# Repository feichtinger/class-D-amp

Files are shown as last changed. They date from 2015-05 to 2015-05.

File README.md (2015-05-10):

# class-D amplifier

This is a construction kit for a neat 2x5W class-D stereo amplifier.

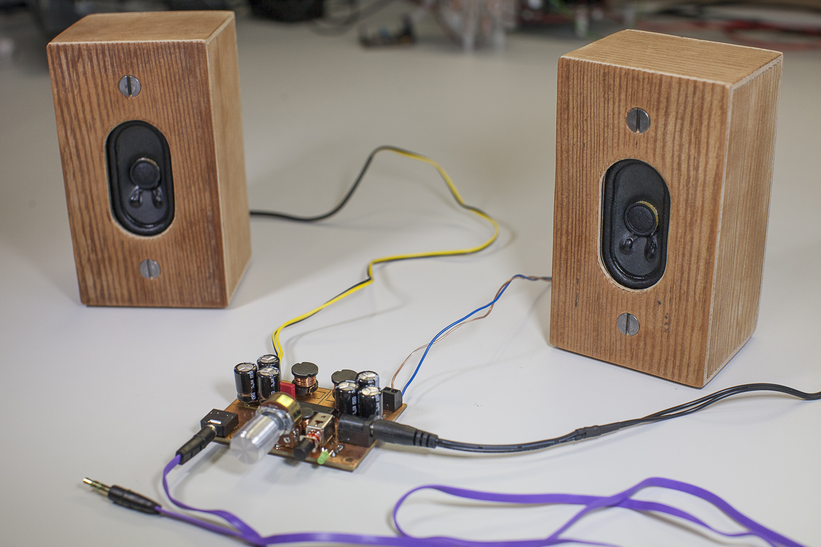
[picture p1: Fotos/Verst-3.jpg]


## purpose
This kit was developed together with Thomas Voglhuber at the [Insitute for Microelectronics and Microsensors](http://www.ime.jku.at) at the Johannes Kepler University.

It is especially designed to be easy to solder even for beginners and may be used for workshops with students or trainees.

The kit provides all components (including power supply and a pair of speakers) that are necessary to build a cute homemade stereo system.

## technical details
The circuit is based on a TPA3125D2 chip with only a view minor extensions such as volume controll and a power switch. Due to the digital operation principle the amplifier reaches a good performance with very low power disspation. Although the circuit was designed for 16 Ohm speakers the chip and the circuit can easily handle even 4 Ohm speakers to gain more output power without the need of a heatsink.

The schematic and PCB layout was made using [KiCad](http://www.kicad-pcb.org/display/KICAD/KiCad+EDA+Software+Suite). The PCB layout was designed with respect to the basic rules of power electronics such as separation of power and signal current traces and keeping high frequency current traces as short as possible.

This is open hardware, so feel free to build, change and improve things!

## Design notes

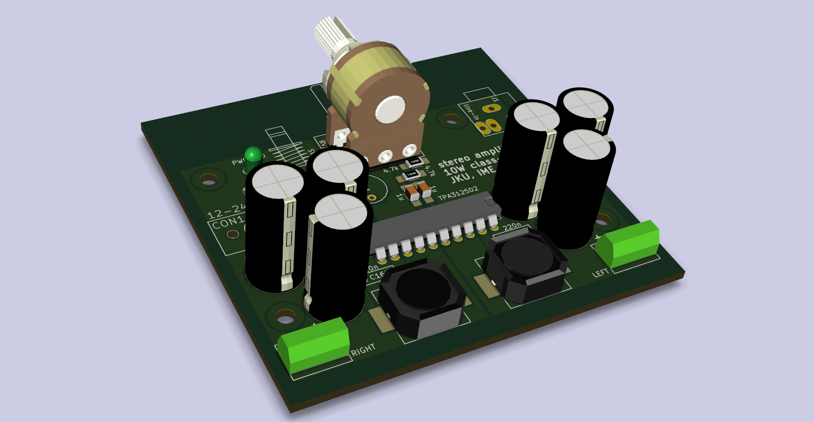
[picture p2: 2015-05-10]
KiCad/images/class-D_amp_3D_2.png

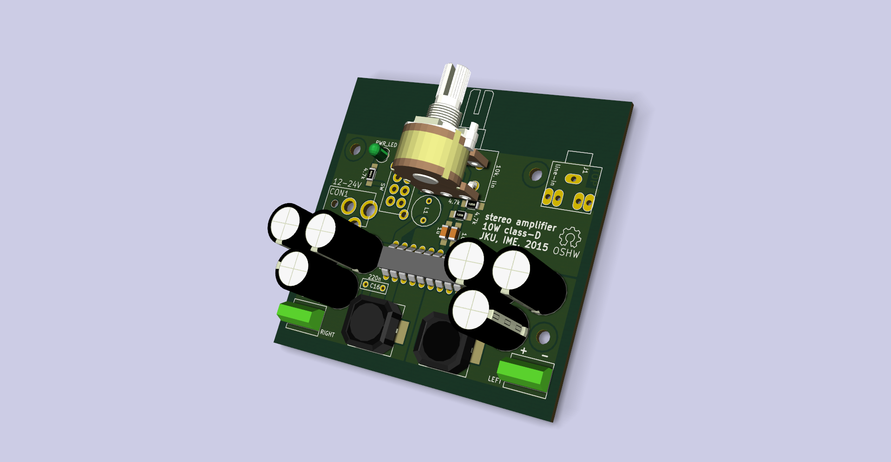
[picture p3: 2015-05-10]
KiCad/images/class-D_amp_3D_1.png

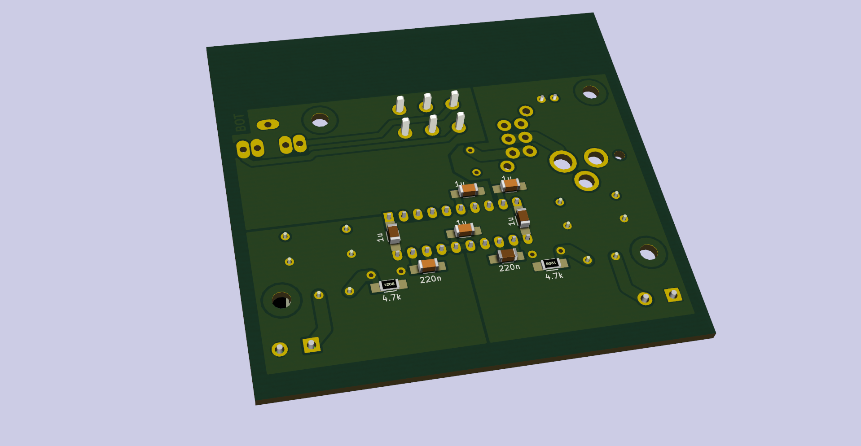
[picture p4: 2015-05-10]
KiCad/images/class-D_amp_3D_3.png

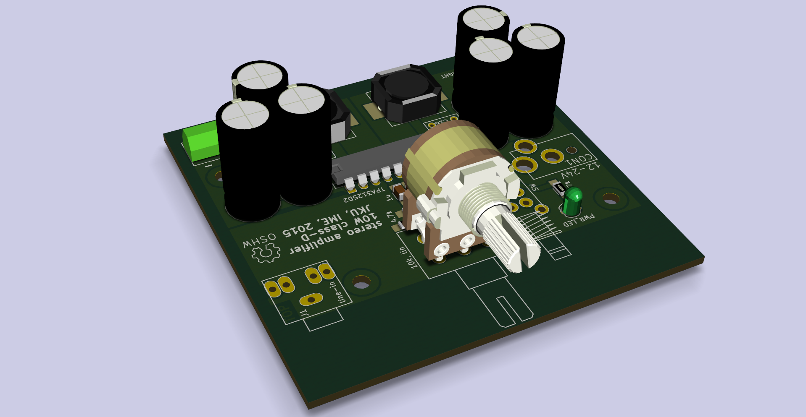
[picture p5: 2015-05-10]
KiCad/images/class-D_amp_3D_4.png

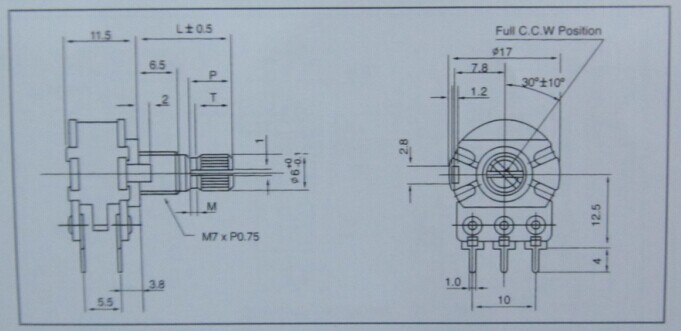
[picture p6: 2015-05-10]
Datenblätter/stereo_poti.jpg

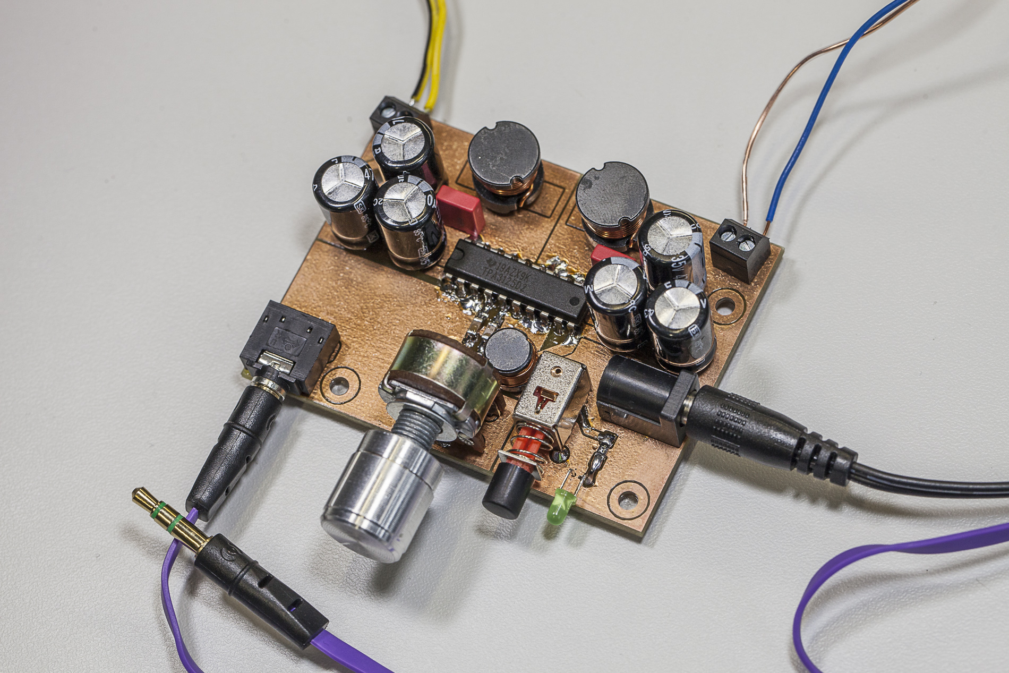
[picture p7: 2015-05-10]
Fotos/Verst-4.jpg

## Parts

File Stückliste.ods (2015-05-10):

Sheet: Tabelle1
Stückliste für class-D Verstärker
Stückzahl | Beschreibung | Wert | Abmessungen (in mm) | Händler | Artikelnummer | Stück gesamt | Einzelpreis € | Gesamtpreis €
5 | Widerstand | 4.7k | 1206 | Reichelt | SMD 1/4W 4,7K | 250 | 0,026 | 0,13
9 | Keramikkondensator | 1u | 1206 | Reichelt | X7R-G1206 1,0/50 | 450 | 0,04 | 0,36
2 | Folienkondensator, MKT | 220n | RM 5, 2.5x7.5 | Reichelt | MKS-2-5 220N | 100 | 0,112 | 0,224
6 | Alu-Elko | 470u, 35V | RM 5, d10x20 | Reichelt | RAD 470/35 | 300 | 0,081 | 0,486
2 | Printklemme, 2 polig |  | RM 3.5 | Reichelt | AKL 059-02 | 100 | 0,24 | 0,48
1 | Ferritdrossel, stehend | 330u | RM 5, d8 | Reichelt | L-07HCP 330µ | 50 | 0,3 | 0,3
1 | LED, grün |  | RM2.5, d3 | Reichelt | LED 3MM GN | 50 | 0,061 | 0,061
1 | 3.5mm Klinkenbuchse |  |  | ebay |  | 50 | 0,129 | 0,129
1 | Stereopoti, linear | 10k | d15 | ebay |  | 50 | 0,4194 | 0,4194
1 | TPA3125D2 |  |  | ? |  | 50 | 1,818 | 1,818
2 | Ferritdrossel, stehend | 47u | RM 7, d12.5 | Reichelt | L-09HCP 47µ | 100 | 0,54 | 1,08
1 | DC-Buchse (Hohlstecker) | d5.5, d2.1 |  | ebay |  | 50 | 0,0956 | 0,0956
1 | Druck-Schalter DPDT | 12x6 |  | ebay |  | 50 | 0,364 | 0,364
33
andere Teile (nicht in Netzliste enthalten)
1 | Netzteil | 24V DC |  | ebay |  | 50 | 3,8256 | 3,8256
1 | Lautsprecherpaar | 16 Ohm, 5W |  | Pollin |  | 50 | 0,95 | 0,95
1 | Potiknopf |  |  | ebay |  | 50 | 0,1754 | 0,1754
1 | Schalterknopf |  |  | ebay |  | 50 | 0,1404 | 0,1404
1 | 3.5mm Klinkenkabel |  |  | ebay |  | 50 | 0,4738 | 0,4738
1 | Platine |  | 54x72 | multi-cb |  | 50 | 3,42 | 3,42
4 | Klebefüße |  |  | Reichelt | GF 63 | 3 | 0,047 | 0,188 | Achtung: eine Packung enthält 75 Stück!
 |  |  |  |  | Gesamtpreis: |  |  | 15,1202
Stückzahl: | 50

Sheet: Tabelle2
SMD 1/4W 4,7K | 250
X7R-G1206 1,0/50 | 450
MKS-2-5 220N | 100
RAD 470/35 | 300
AKL 059-02 | 100
L-07HCP 330µ | 50
LED 3MM GN | 50
L-09HCP 47µ | 100
GF 63 | 3

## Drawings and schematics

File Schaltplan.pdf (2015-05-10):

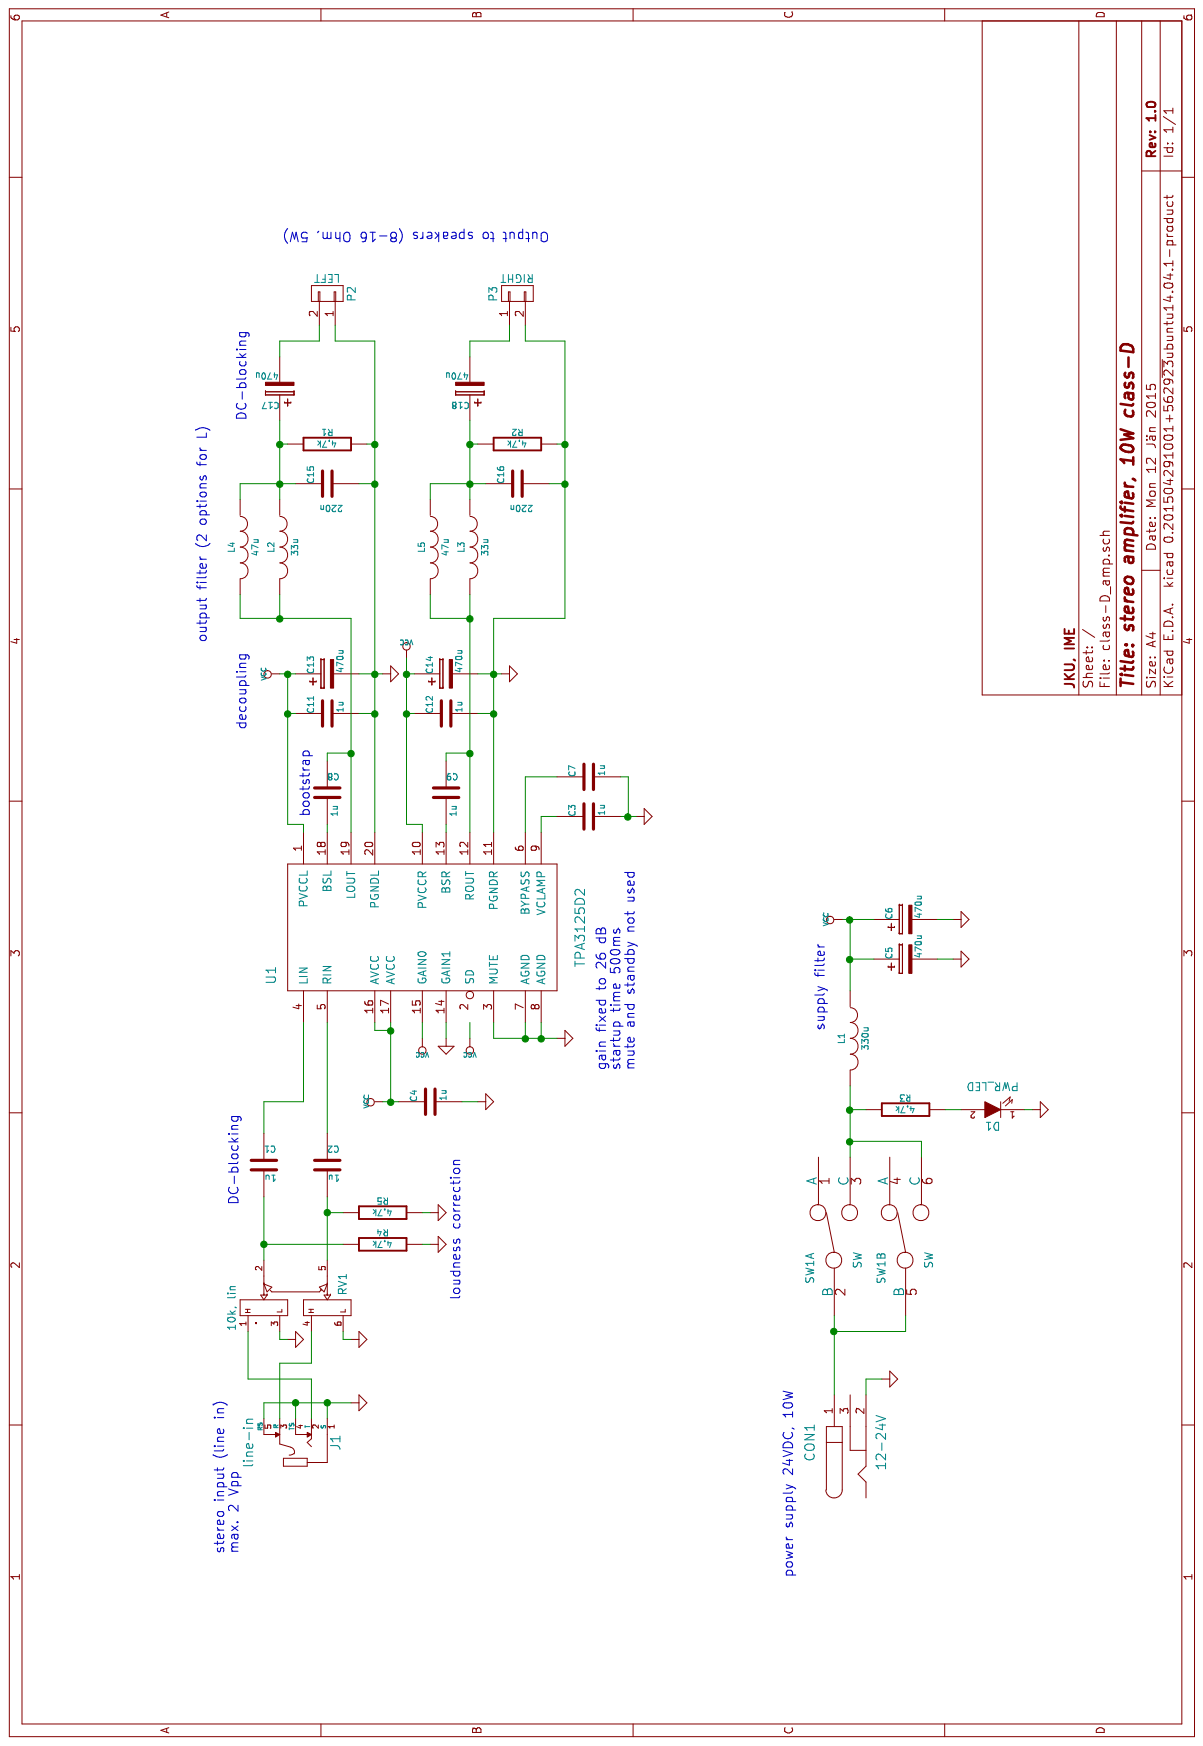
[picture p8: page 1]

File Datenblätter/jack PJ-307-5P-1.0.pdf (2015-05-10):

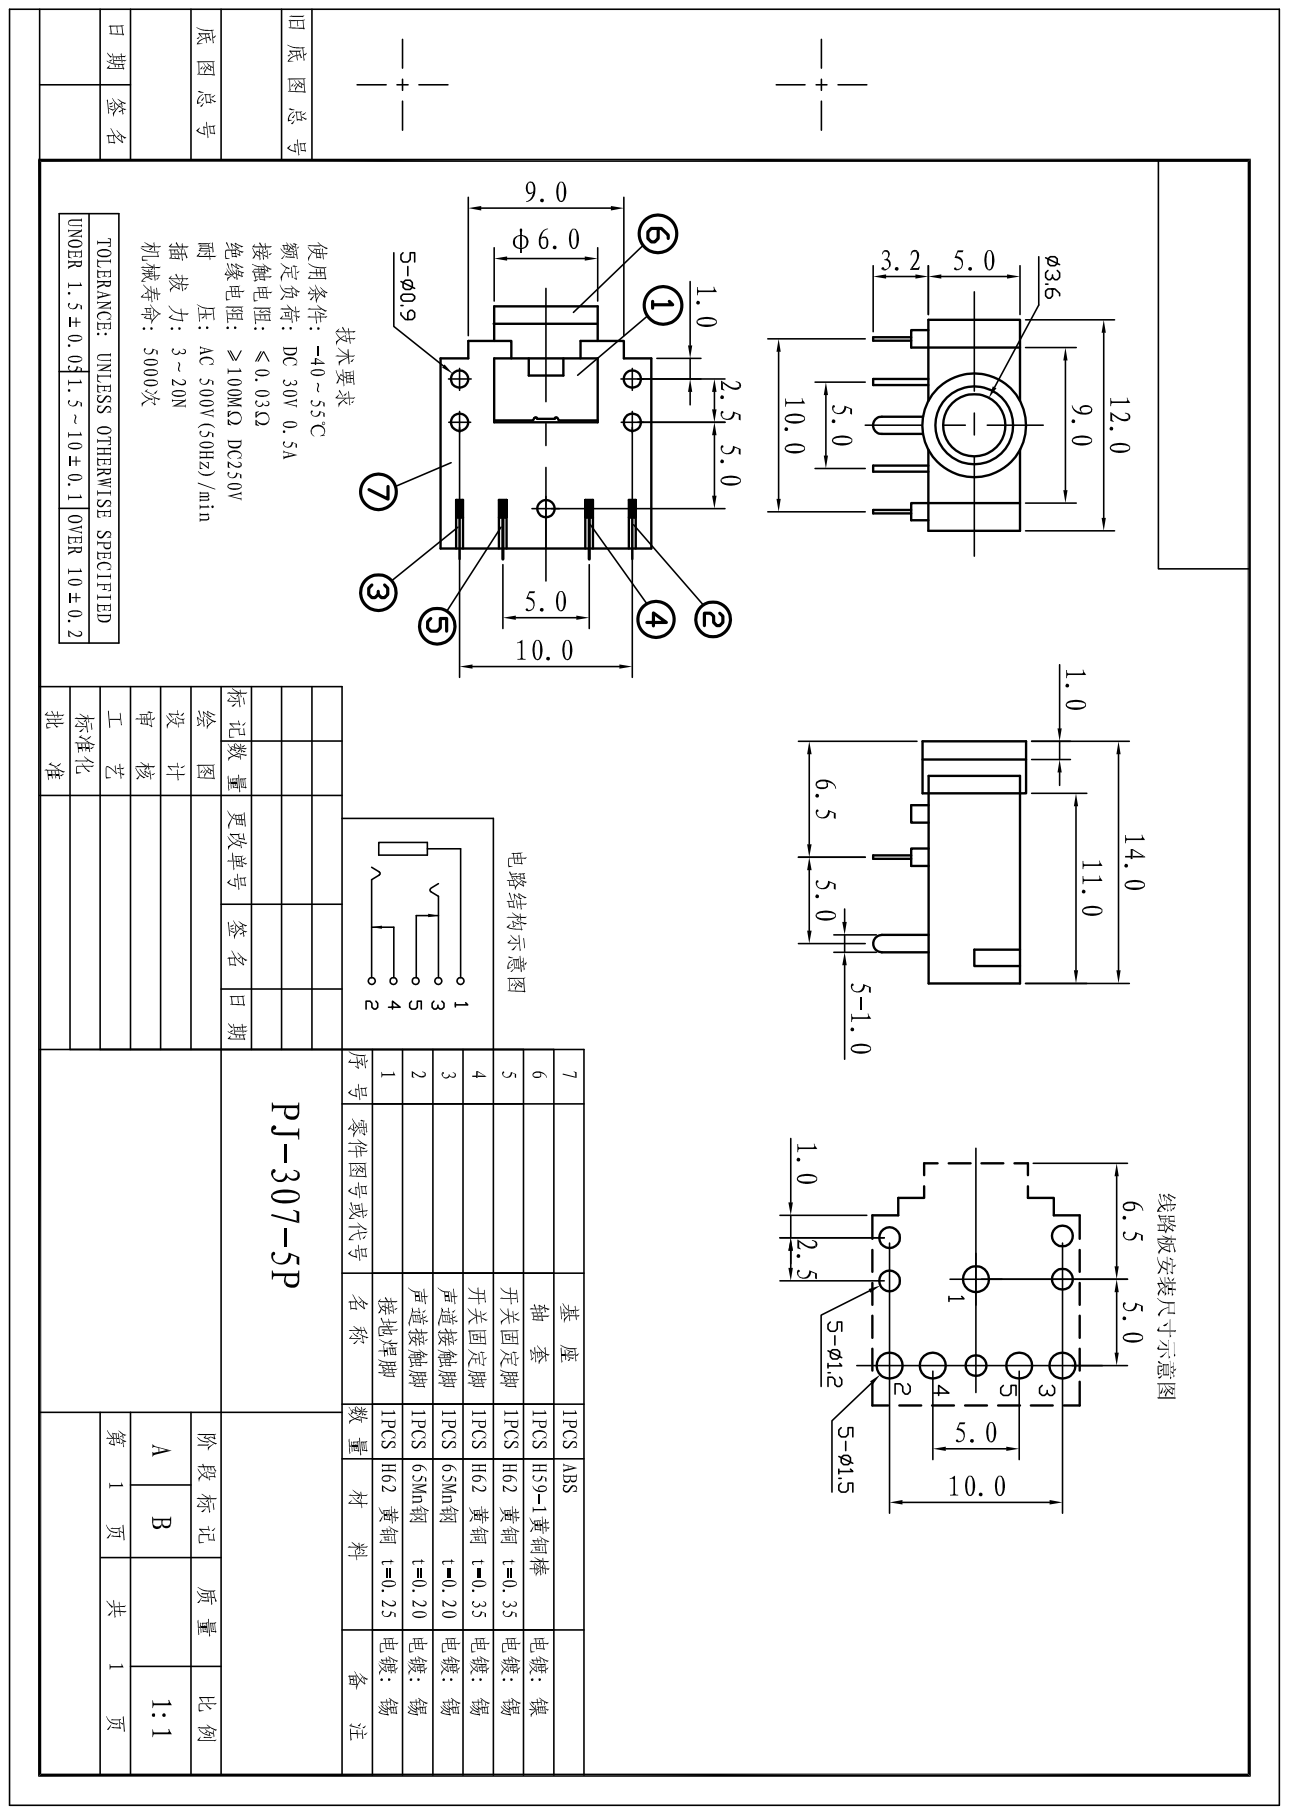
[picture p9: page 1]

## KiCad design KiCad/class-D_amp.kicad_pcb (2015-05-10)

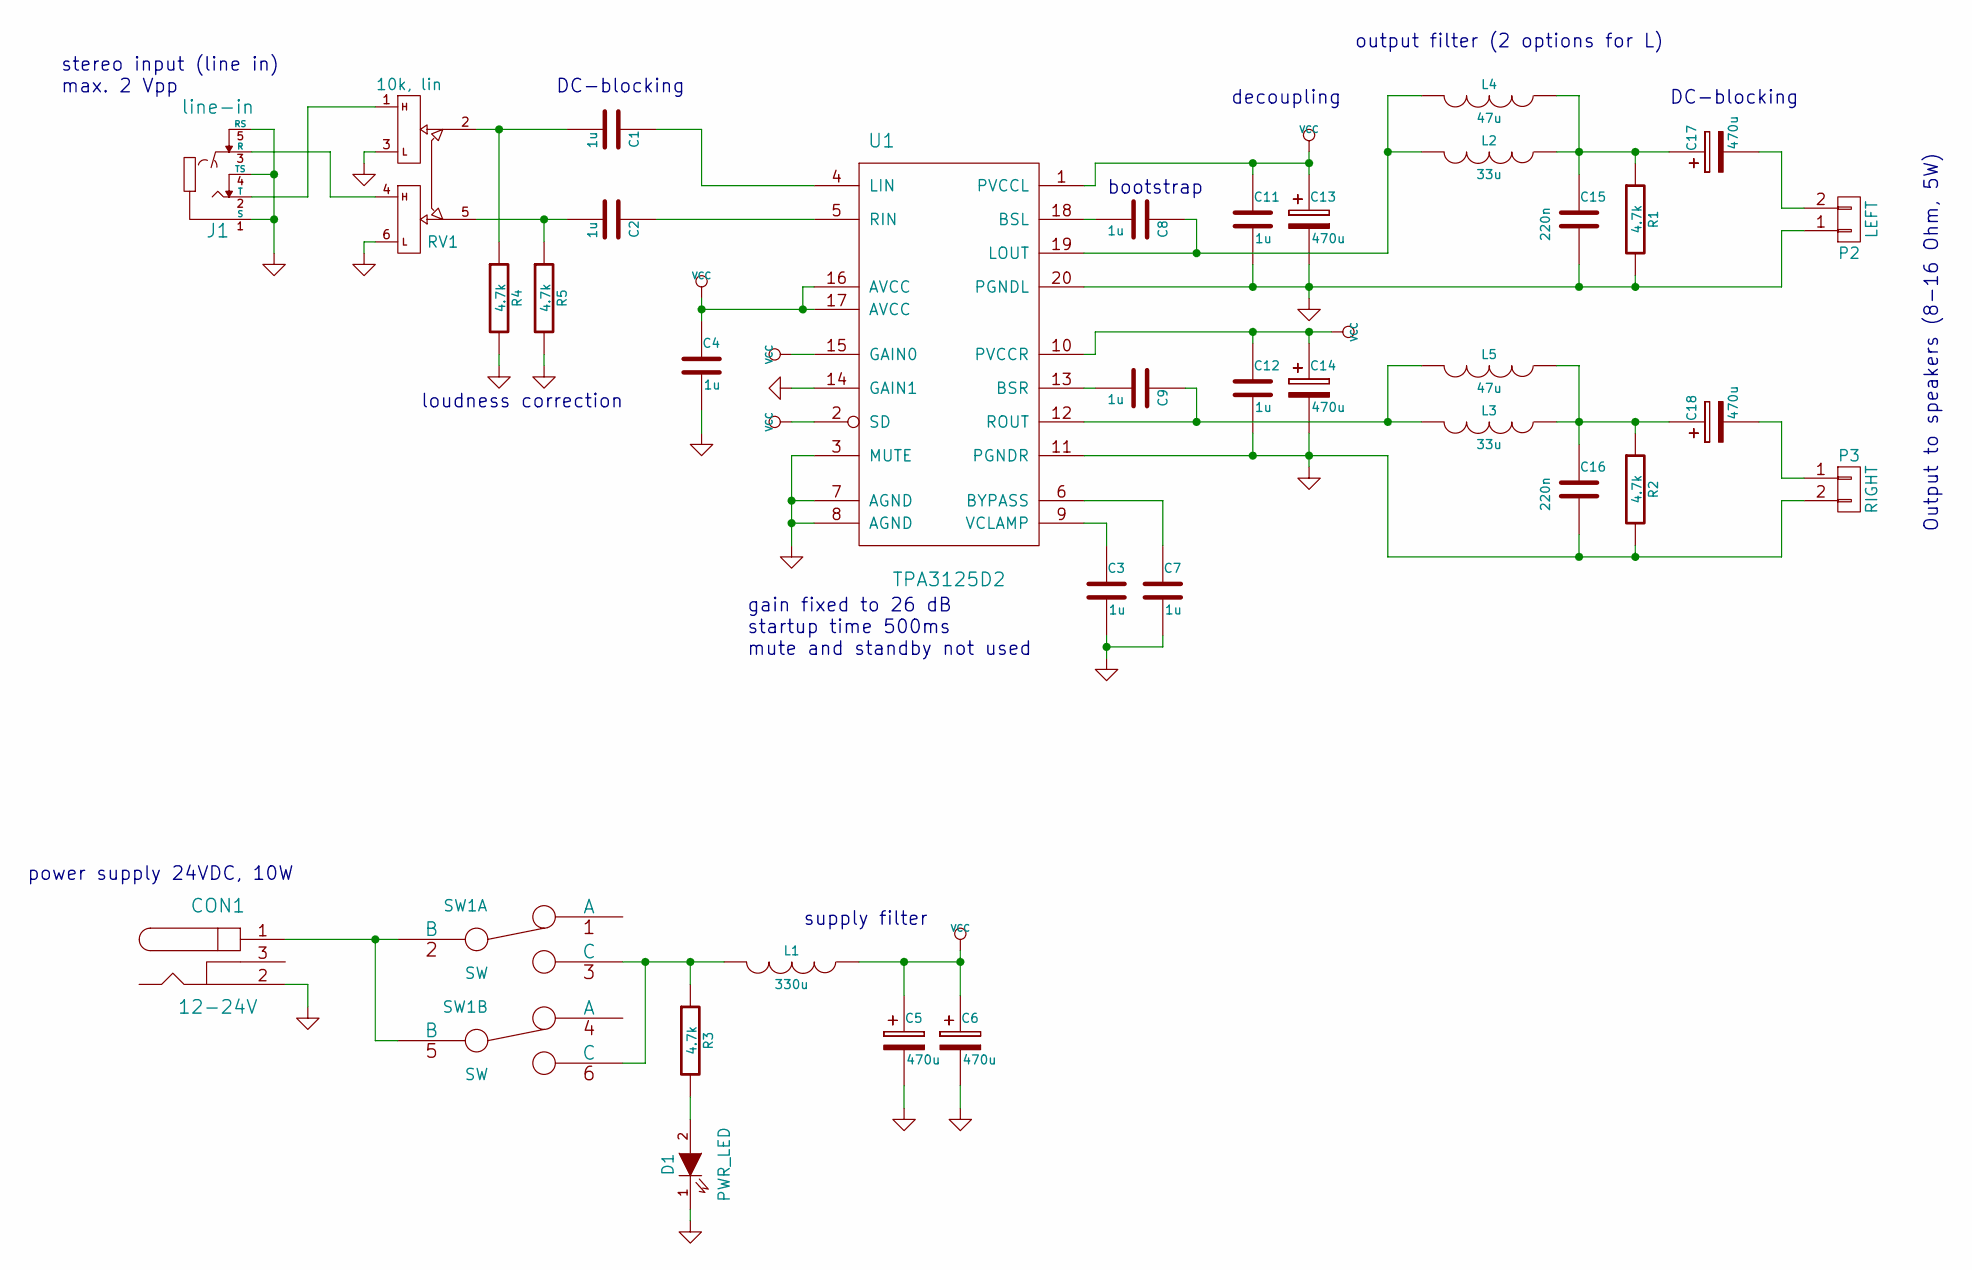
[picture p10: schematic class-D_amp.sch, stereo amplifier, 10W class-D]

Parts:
C1, C2, C3, C4, C7, C8, C9, C11, C12: 1u; C_1206_HandSoldering
C5, C6, C13, C14, C17, C18: 470u; Elko_vert_20x10mm_RM5_CopperClear
C15, C16: 220n; Capacitor7x2.5RM5
CON1: 12-24V; DC-conn
D1: PWR_LED; LED-3MM
J1: line-in; stereo_jack_3.5mm
L1: 330u; Neosid_Inductor_Sd8
L2, L3: 33u; Choke_SMD_12x12mm_h4.5mm_handsolder
L4, L5: 47u; inductor_d12.5_RM7
P2: LEFT; pt_1,5-2-3,5-h
P3: RIGHT; pt_1,5-2-3,5-h
R1, R2, R3, R4, R5: 4.7k; R_1206_HandSoldering
RV1: 10k, lin; Potentiometer_double_15mm
SW1: SW; DPDT_push_switch
U1: TPA3125D2; DIP-20__300_ELL

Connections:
GND: C3.2, C4.2, C5.2, C6.2, C7.2, C11.2, C12.2, C13.2, C14.2, C15.2, C16.2, CON1.2, D1.1 (K), J1.1 (S), J1.4 (TS), J1.5 (RS), P2.1, P3.2, R1.2, R2.2, R4.2, R5.2, RV1.3, RV1.6, U1.3 (MUTE), U1.7 (AGND), U1.8 (AGND), U1.11 (PGNDR), U1.14 (GAIN1), U1.20 (PGNDL)
unnamed: C1.1, U1.4 (LIN)
unnamed: C1.2, R4.1, RV1.2
unnamed: C2.1, U1.5 (RIN)
unnamed: C2.2, R5.1, RV1.5
unnamed: C3.1, U1.9 (VCLAMP)
unnamed: C7.1, U1.6 (BYPASS)
unnamed: C8.1, L2.2, L4.2, U1.19 (LOUT)
unnamed: C8.2, U1.18 (BSL)
unnamed: C9.1, L3.2, L5.2, U1.12 (ROUT)
unnamed: C9.2, U1.13 (BSR)
unnamed: C15.1, C17.1, L2.1, L4.1, R1.1
unnamed: C16.1, C18.1, L3.1, L5.1, R2.1
unnamed: C17.2, P2.2
unnamed: C18.2, P3.1
unnamed: CON1.1, SW1.2 (B), SW1.5 (B)
unnamed: D1.2 (A), R3.2
unnamed: J1.2 (T), RV1.1
unnamed: J1.3 (R), RV1.4
unnamed: L1.2, R3.1, SW1.3 (C), SW1.6 (C)
VCC: C4.1, C5.1, C6.1, C11.1, C12.1, C13.1, C14.1, L1.1, U1.1 (PVCCL), U1.2 (SD), U1.10 (PVCCR), U1.15 (GAIN0), U1.16 (AVCC), U1.17 (AVCC)

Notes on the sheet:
bootstrap
decoupling
output filter (2 options for L)
DC-blocking
Output to speakers (8-16 Ohm, 5W)
stereo input (line in) max. 2 Vpp
power supply 24VDC, 10W
supply filter
gain fixed to 26 dB startup time 500ms mute and standby not used
loudness correction

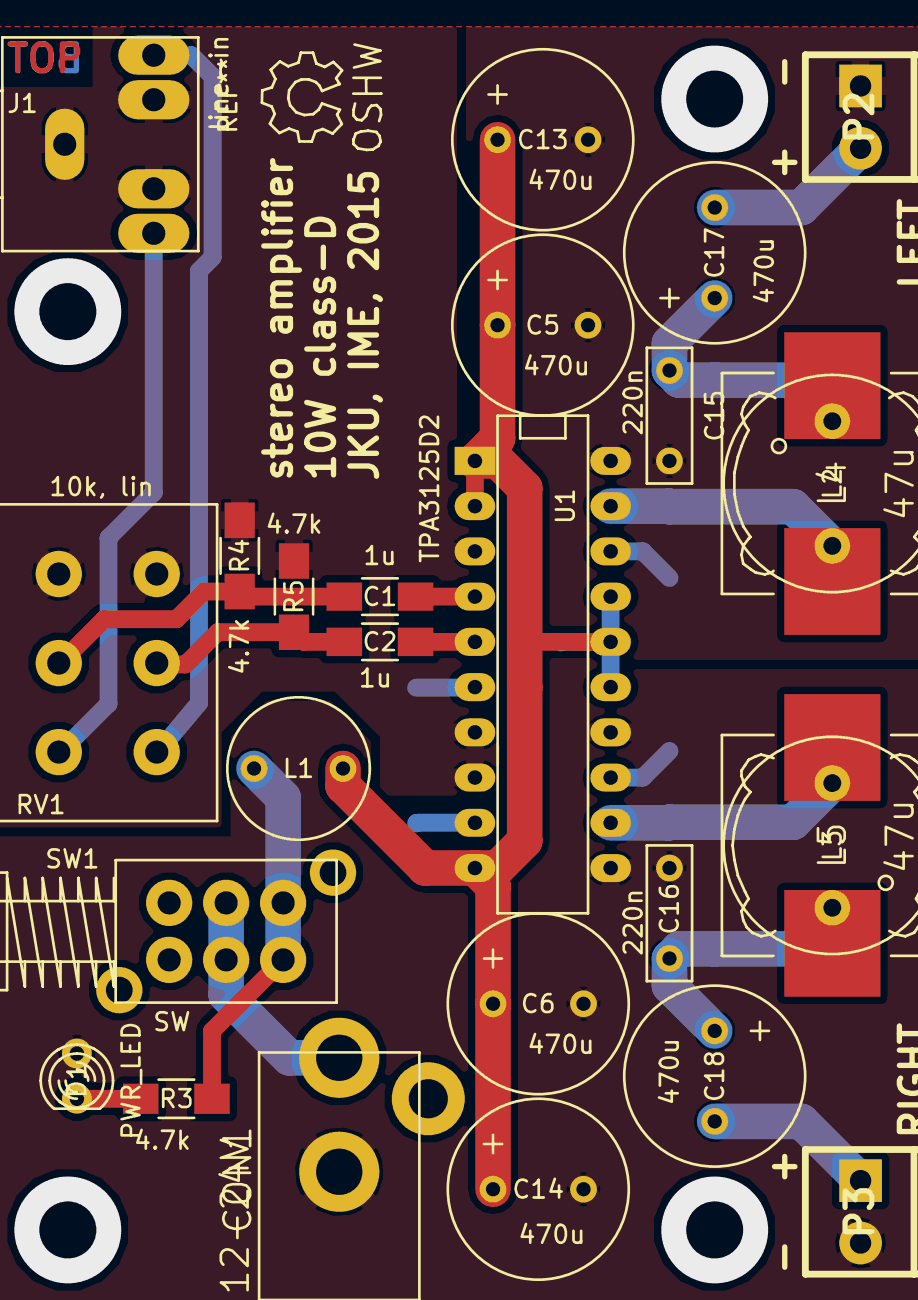
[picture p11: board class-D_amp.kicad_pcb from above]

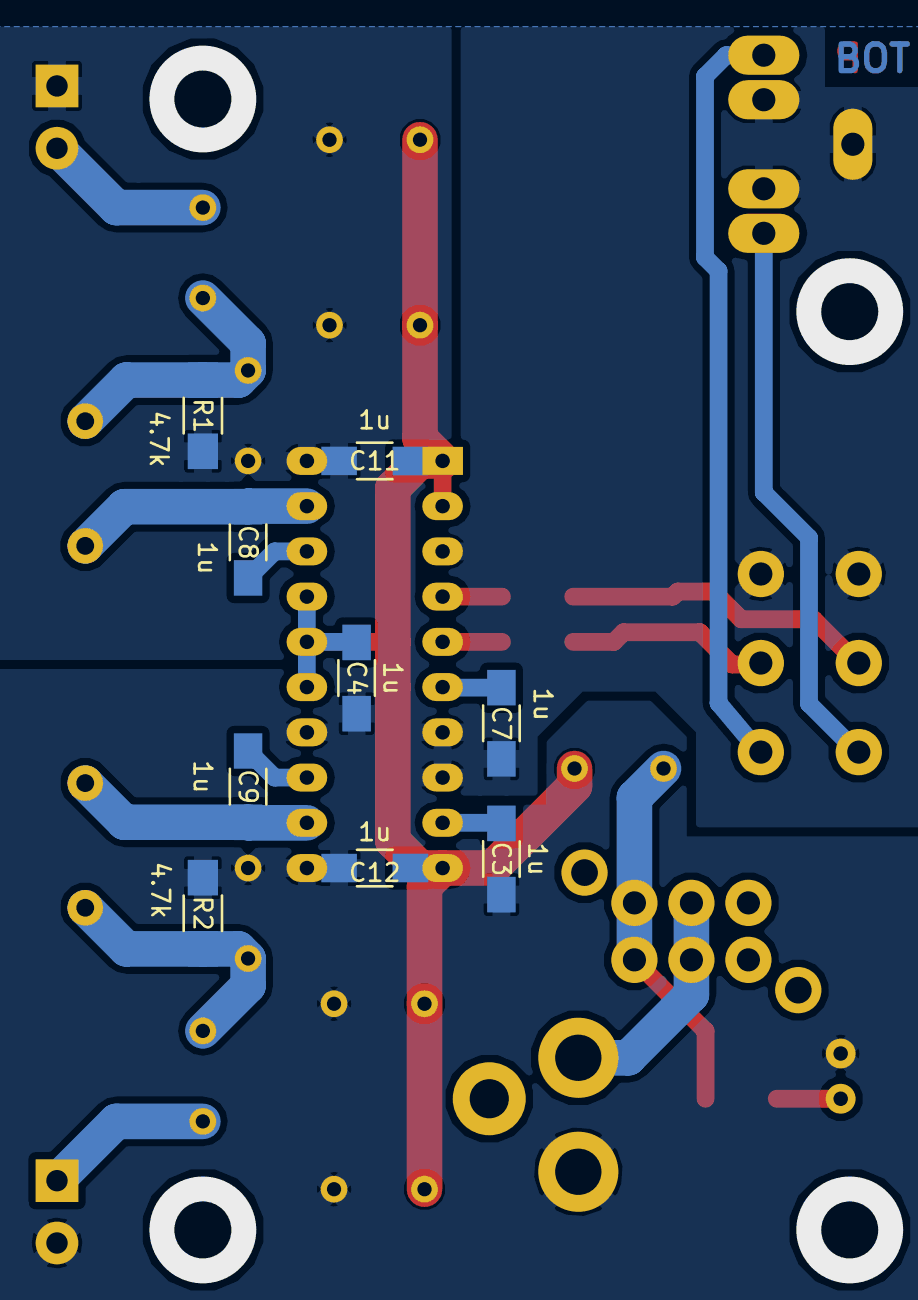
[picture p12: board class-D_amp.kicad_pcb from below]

Board: 2 copper layers, 35 parts (9 on the bottom side), 21 nets.
